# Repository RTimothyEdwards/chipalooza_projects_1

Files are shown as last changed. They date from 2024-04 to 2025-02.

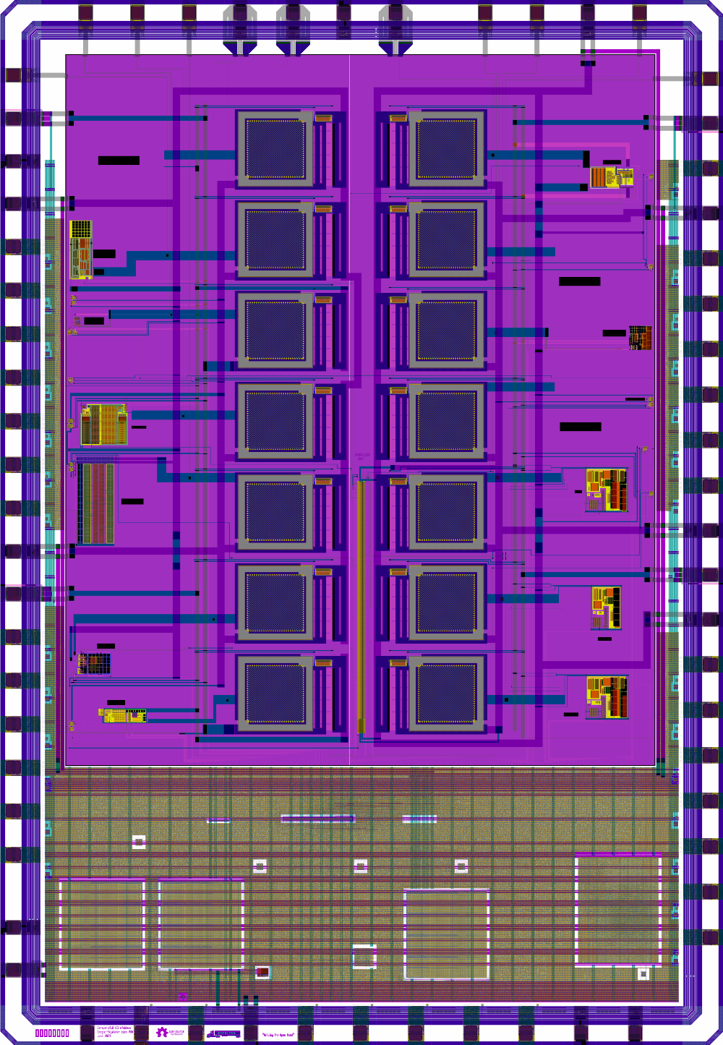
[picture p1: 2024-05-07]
doc/caravan.png

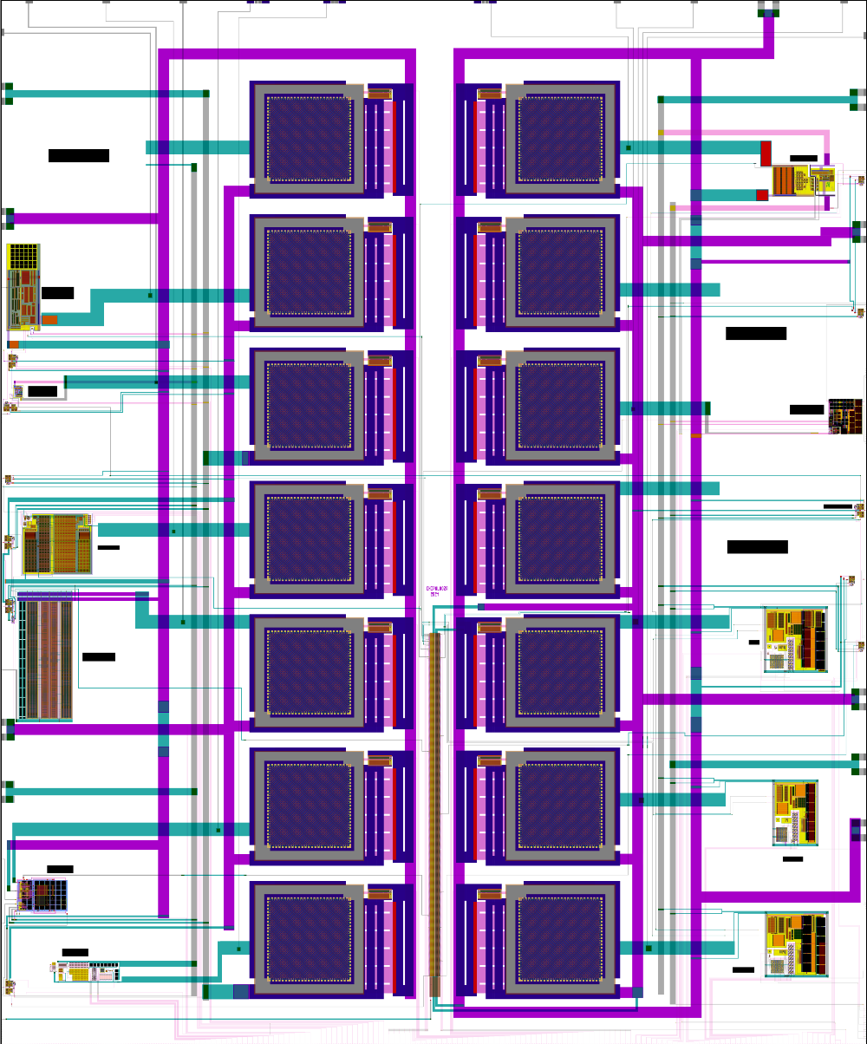
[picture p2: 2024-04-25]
doc/chipalooza_projects_1.png

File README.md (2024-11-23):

# Caravel Analog User

  

---

| :exclamation: Important Note            |
|-----------------------------------------|

This is the first test chip from the Chipalooza challenge 2024.
11 designs made it on the April tapeout.

The projects on this tapeout and their source URLs are as follows:

	1.  	High-speed crystal oscillator (4-16MHz)
		hsxo-cpz1 
		https://github.com/efabless/sky130_ht_ip__hsxo_cpz1 (forked)
		https://github.com/htfab/hsxo-cpz1
		Tamas Hubai

	2.  	Brownout detector
		sky130_ajc_ip__brownout
		https://github.com/efabless/sky130_ajc_ip__brownout (forked)
		https://github.com/ajcci/sky130_ajc_ip__brownout
		Robin Tsang

	3.  	Overvoltage detector
		sky130_ajc_ip__overvoltage
		https://github.com/efabless/sky130_ajc_ip__overvoltage (forked)
		https://github.com/ajcci/sky130_ajc_ip__overvoltage
		Robin Tsang

	4.  	Power-on-Reset
		sky130_ajc_ip__por
		https://github.com/efabless/sky130_ajc_ip__por (forked)
		https://github.com/ajcci/sky130_ajc_ip__por
		Robin Tsang

	5.  	Comparator
		sky130_ak_ip__comparator
		https://github.com/efabless/sky130_ak_ip__comparator (forked)
		https://github.com/andrewkkang/sky130_ak_ip__comparator
		Andrew Kang

	6.  	Low-speed crystal oscillator (32kHz)
		sky130_be_ip__lsxo
		https://github.com/efabless/sky130_be_ip__lsxo (forked)
		https://github.com/b-etz/sky130_be_ip__lsxo
		Brady Etz

	7.  	Temperature sensor
		sky130_od_ip__tempsensor
		https://github.com/efabless/sky130_od_ip__tempsensor (forked)
		https://github.com/ordicker/sky130_od_ip__tempsensor
		Or Dicker

	8.  	Low power operational amplifier
		sky130_rodovalho_ip__lpopamp
		https://github.com/efabless/sky130_rodovalho_ip__lpopamp (forked)
		https://github.com/lhrodovalho/sky130_rodovalho_ip__lpopamp
		Luis Henrique Rodovalho

	9.  	High gain-bandwidth operational amplifier
		sky130_td_ip__opamp_hp
		https://github.com/efabless/sky130_td_ip__opamp_hp (forked)
		https://github.com/tdextrous/sky130_td_ip__opamp_hp
		Thomas Dexter

	10. 	Overvoltage detector
		sky130_vbl_ip__overvoltage
		https://github.com/efabless/sky130_vbl_ip__overvoltage (forked)
		https://github.com/LDFranck/sky130_vbl_ip__overvoltage
		Lucas Franck, William Orlato, and Toni Tejada

	11.	Bandgap (not from Chipalooza)
		bandgap
		https://github.com/efabless/sky130_cw_ip (forked)
		https://github.com/christoph-weiser/mpw7
		Christoph Weiser

	12.	Power FET (not from Chipalooza)
		power_stage
		(in this repository)
		Weston Braun

	13.	Bias current generator (not from Chipalooza)
		bias_generator
		(in this repository)
		Tim Edwards

	14.	Ground-isolated analog switch (not from Chipalooza)
		isolated_switch_ena1v8
		(in this repository)
		Tim Edwards

(Documentation, including test instructions, still needs to be completed)

:---: | :---

Building:

Get the dependencies above by doing "make get_ip_blocks" in the top level
directory.  This will clone all of the IP blocks from various github
repository sources into the "dependencies" directory.

The test chip is generated in magic by running magic in the mag/ directory
and issuing the command "source construct_testchip.tcl".

Verifying:

In the top level directory, do "make run-precheck".  This requires at
least setting environment variables PDK_ROOT, PDK, and PRECHECK_ROOT.
If the PDK is installed with open_pdks, then PRECHECK_ROOT can be set
to open_pdks/sources/precheck_sky130.

Testing:

All projects are connected either to the logic analyzer (128 I/O bits) or
the GPIO pins.  Generally speaking, static control bits (enable and trim,
for example) are logic analyzer outputs.  Dynamic digital bits are routed
to GPIO digital outputs, while analog I/O are routed to the analog
connections of the GPIO.

Each power supply is routed through gated power pFETs so each project
can be powered individually.  Each power supply connection internally
is routed to a bare analog pin for monitoring the supply voltage of
the project.  Be aware that these are ESD-sensitive points!

Power supplies are enabled through a differential switch.  Due to
time constraints, the differential signals (enable, !enable) were
both routed to the logic analyzer.  Both bits need to be set
correctly.

Most projects take current biases which are distributed by a central
bias current generator circuit.  Various test point bias currents are
connected through ground-isolated switches to GPIO analog signals.

Project circuit blocks are described below, starting at the top left
corner of the chip and working counterclockwise around the chip
perimeter.

---

High Gain-Bandwidth Operational Amplifier  
(Thomas Dexter)  
Enable:  la_data_in[37]  
Bias:    100nA	when selected  
	Selection: la_data_in[40] = 0  
Upstream analog power supply: vdda2/vssa2  
Upstream digital power supply: vccd2/vssd2  
Power supply monitor:  io_analog[10] (pin GPIO 24) "mon_hgbw_opamp"  
Power supply enable: la_data_in[60]  
Amp output:  gpio_noesd[7] (pin GPIO 25) "hgbw_opamp_out"  
Amp negative input: gpio_analog[8] (pin GPIO 26) "hgbw_opamp_in-" when selected  
	Selection: la_data_in[36] = 1  
Amp positive input: gpio_analog[9] (pin GPIO 27) "hgbw_opamp_in+" when selected  
	Selection: la_data_in[34] = 1  

---

Temperature sensor  
(Or Dicker)  
Enable: la_data_in[35]  
Bias:  gpio_noesd[2] (pin GPIO 9) "1.2V_bias" (nominally 1.2V) when selected  
	Selection: la_data_in[122] = 1  
Upstream digital power supply: vccd2/vssd2  
Power supply monitor: io_analog[9] (pin GPIO 23) "mon_temp_sense"  
Power supply enable: la_data_in[58]  
Vbe1_out: gpio_analog[9] (pin GPIO 27) "temp_sense_vbe1" when selected  
	Selection: la_data_in[34] = 0  
Vbe2_out: gpio_analog[8] (pin GPIO 26) "temp_sense_vbe2" when selected  
	Selection: la_data_in[36] = 0  

---

Comparator  
(Andrew Kang)  
Enable: la_data_in[28]  
Hysteresis: la_data_in[29:30]  
Trim: la_data_in[25:27],la_data_in[33:31]  
Bias:	400nA	when selected  
	Selection:  la_data_in[44] = 0  
Upstream analog power supply: vdda2/vssa2  
Upstream digital power supply: vccd2/vssd2  
Power supply monitor: io_analog[8] (pin GPIO 22) "mon_comparator"  
Power supply enable: la_data_in[56]  
Comparator output: io_out[17] (pin GPIO 28) "comparator_out"  
Comparator negative input:  gpio_analog[12] (pin GPIO 30) "comparator_in-" when selected  
	Selection: la_data_in[22] = 1  
Comparator positive input:  gpio_analog[11] (pin GPIO 29) "comparator_in+" when selected  
	Selection: la_data_in[23] = 1  
	
---

Low power operational amplifier  
(Luis Henrique Rodovalho)  
Enable: la_data_in[21]  
Bias:  10uA when selected  
	Selection:  la_data_in[46] = 0  
Upstream analog power supply: vdda2/vssa2  
Upstream digital power supply: vccd2/vssd2  
Power supply monitor: io_analog[7] (pin GPIO 21) "mon_lpopamp"  
Power supply enable: la_data_in[54]  
Amplifier output:  gpio_analog[13] (pin GPIO 31) "lpopamp_out"  
Amplifier negative input: gpio_analog[11] (pin GPIO 29) "lpopamp_in-" when selected  
	Selection: la_data_in[23] = 0  
Amplifier positive input: gpio_analog[12] (pin GPIO 30) "lpopamp_in+" when selected  
	Selection: la_data_in[22] = 0  

---

High speed crystal oscillator  
(Tamas Hubai)  
Enable: la_data_in[19]  
Standby: la_data_in[20]  
Bias:  10uA when selected  
	Selection: la_data_in[47] = 0  
Upstream analog power supply: vdda2/vssa2  
Upstream digital power supply: vccd2/vssd2  
Power supply monitor: io_analog[6] (pin GPIO 20) "mon_hsxo"  
Power supply enable:  la_data_in[52]  
Oscillator out:  io_out[23] (pin GPIO 34) "hsxo_out"  
Crystal Xin:  gpio_analog[14] (pin GPIO 32) "hsxo_xin"  
Crystal Xout: gpio_analog[15] (pin GPIO 33) "hsxo_xout"  

---

Bandgap (Christoph Weiser)  
Enable: none (enable via power supply)  
Bias:  self-biased  
Trim: la_data_in[9,8,10,7,11,6,12,5,13,4,14,3,15,2,16,1]  
Upstream digital power supply: vccd2/vssd2  
Power supply monitor: io_analog[5] (pin GPIO 19) "mon_bandgap"  
Power supply enable: la_data_in[50]  
Bandgap output:  gpio_analog[16] (pin GPIO 34) "bandgap_out" when selected  
	Selection:  la_data_in[18] = 1  

---

Brownout detector (Robin Tsang)  
Enable: la_data_in[109]  
Bias: gpio_noesd[2] (pin GPIO 9) "1.2V_bias" (nominally 1.2V) when selected  
	Selection: la_data_in[122] = 0  
Bias: 200nA when selected  
	Selection: la_data_in[43] = 0  
Trip point select (otrip):  la_data_in[112:113,111]  
Trip point select (vtrip):  la_data_in[107:106,108]  
Force enable RC osc: la_data_in[115]  
Force disable RC osc: la_data_in[114]  
Force short oneshot: la_data_in[116]  
Current source select: la_data_in[110]  
Upstream analog power supply: vdda1/vssa1  
Upstream digital power supply: vccd1/vssd1  
Power supply monitor: io_analog[0] (pin GPIO 14) "mon_brownout"  
Power supply enable: la_data_in[77]  
Outb: io_out[0] (pin GPIO 0) "brownout_outb"  
Dcomp: io_out[1] (pin GPIO 1) "brownout_dcomp"  
Vunder: io_out[5] (pin GPIO 5) "brownout_vunder"  
Timed out: la_data_out[117]  

---

Overvoltage detector (Robin Tsang)  
Enable: la_data_in[100]  
Bias: gpio_noesd[2] (pin GPIO 9) "1.2V_bias" (nominally 1.2V) when selected  
	Selection: la_data_in[122] = 0  
Bias: 200nA when selected  
	Selection: la_data_in[42] = 0  
Trip point select (otrip):  la_data_in[105:102]  
Current source select: la_data_in[101]  
Upstream analog power supply: vdda1/vssa1  
Upstream digital power supply: vccd1/vssd1  
Power supply monitor: io_analog[1] (pin GPIO 15) "mon_overvoltage1"  
Power supply enable: la_data_in[75]  
Ovout: io_out[6] (pin GPIO 6) "overvoltage1_ovout"  

---

Power-on-reset (Robin Tsang)  
Bias: gpio_noesd[2] (pin GPIO 9) "1.2V_bias" (nominally 1.2V) when selected  
	Selection: la_data_in[122] = 0  
Bias: 200nA when selected  
	Selection: la_data_in[41] = 0  
Trip point select (otrip): la_data_in[96:98]  
Force PDN: la_data_in[94]  
Force enable RC osc: la_data_in[93]  
Force disable RC osc: la_data_in[92]  
Force short oneshot: la_data_in[99]  
Current source select: la_data_in[95]  
Upstream analog power supply: vdda1/vssa1  
Upstream digital power supply: vccd1/vssd1  
Power supply monitor: io_analog[2] (pin GPIO 16) "mon_por"  
Power supply enable: la_data_in[73]  
POR: io_out[7] (pin GPIO 7) "por_out"  
PORb: io_out[8] (pin GPIO 8) "por_outb"  
Osc_clk: io_out[3] (pin GPIO 3) "por_osc_clk"  
Dcomp: io_out[2] (pin GPIO 2) "por_dcomp"  
Pwup_filt: io_out[4] (pin GPIO 4) "por_pwup_filt"  
Startup timed out: la_data_out[120]  
POR timed out: la_data_out[119]  

---

Low-speed (32kHz) crystal oscillator (Brady Etz)  
Enable: la_data_in[86]  
Standby: la_data_in[85]  
Bias: 50nA when selected  
	Selection: la_data_in[39] = 0  
Upstream analog power supply: vdda1/vssa1  
Upstream digital power supply: vccd1/vssd1  
Power supply monitor: io_analog[3] (pin GPIO 17) "mon_lsxo"  
Power supply enable: la_data_in[69]  
Dout: io_out[12] (pin GPIO 12) "lsxo_out"  
Crystal XIn: gpio_noesd[3] (pin GPIO 10) "lsxo_xin"  
Crystal XOut: gpio_noesd[4] (pin GPIO 11) "lsxs_xout"  

---

Overvoltage detector (Lucas Franck & William Orlato)  
Enable: la_data_in[91]  
Bias: gpio_noesd[2] (pin GPIO 9) "1.2V_bias" (nominally 1.2V) when selected  
	Selection: la_data_in[122] = 1  
Bias: 600nA when selected  
	Selection: la_data_in[45] = 0  
Trip point select (vtrip): la_data_in[87:90]  
Upstream analog power supply: vdda1/vssa1  
Upstream digital power supply: vccd1/vssd1  
Power supply monitor: io_analog[4] (pin GPIO 18) "mon_overvoltage2"  
Power supply enable: la_data_in[65]  
OVout: io_out[13] (pin GPIO 13) "overvoltage2_out"  

---

All bias currents are regulated by an input bias voltage which is
nominally 3.3V but may be adjusted up or down to trim the bias
(limit max. voltage VDDIO + 0.3V to avoid forward biasing the ESD
diodes into the power supply).  
Bias in: gpio_analog[17] (pin GPIO 35) "bias_trim_in"  

---

Three power FETs are unused but should be kept disabled:  
Enable:  la_data_in[62], la_data_in[67], la_data_in[71]  

---

The bias generator has a master enable signal that will enable
all bias currents:  

Enable bias generator:  la_data_in[79]   

It also has a separate disable signal for the sources (which is
all of the biases used by projects on this chip):  

Disable bias generator sources:  la_data_in[48]   

---

These current sources/sinks are multiplexed to analog pins not otherwise
being used for projects.  The "enable" or "disable" bit enables or disables
the current bias, and "selection" connects it to the associated pin:  

100nA source (test0): gpio_analog[16] (pin GPIO 34) when selected  
	Disable: la_data_in[49]  
	Selection: la_data_in[18] = 0 (at pin)  

100nA source (test1): gpio_analog[10] (pin GPIO 28) when selected  
	Disable: la_data_in[38]  
	Selection: la_data_in[17] = 1 (at pin)  

100nA sink (test1): gpio_analog[6] (pin GPIO 13) when selected  
	Enable:  la_data_in[84]  
	Selection: la_data_in[124] = 1 (at pin)  

3.7uA sink (sink_3700): gpio_analog[5] (pin GPIO 12) when selected  
	Enable:  la_data_in[83]  
	Selection: la_data_in[123] = 1 (at pin)  

5.0uA sink (sink_5000_1): gpio_analog[1] (pin GPIO 8) when selected  
	Enable:  la_data_in[81]  
	Selection: la_data_in[121] = 1 (at pin)  

100nA sink (test0): gpio_analog[0] (pin GPIO 7) when selected  
	Enable:  la_data_in[78]  
	Selection: la_data_in[118] = 1 (at pin)  

---

Refer to [README](docs/source/index.rst) for this sample project documentation.   

Refer to docs/chipalooza_testchip1.pdf (.ps) for a package pinout drawing.  

---

Chip QFN-64 package pinout:

Pin  Signal(s)  
 1   vssa2  
 2   mprj_io[25] hgbw_opamp_out  
 3   mprj_io[26] hgbw_opamp_in- temp_sense_vbe2  
 4   mprj_io[27] hgbw_opamp_in+ temp_sense_vbe1  
 5   mprj_io[28] comparator_out source_100_1  
 6   mprj_io[29] comparator_in+ lpopamp_in-  
 7   mprj_io[30] comparator_in- lpopamp_in+  
 8   mprj_io[31] lpopamp_out  
 9   vdda2  
10   vssd2  
11   mprj_io[32] hsxo_xin  
12   mprj_io[33] hsxo_xout  
13   mprj_io[34] hsxo_out  bandgap_out source_100_0  
14   mprj_io[35] bias_trim_in  
15   mprj_io[36]  
16   mprj_io[37]  
17   vddio  
18   vccd  
19   N/C  
20   vssa  
21   resetb  
22   clock  
23   vssd  
24   flash_csb  
25   flash_clk  
26   flash_io0  
27   flash_io1  
28   gpio  
29   vssio  
30   vdda  
31   mprj_io[0] brownout_outb  
32   mprj_io[1] brownout_dcomp  
37   mprj_io[2] por_dcomp  
34   mprj_io[3] por_osc_clk  
35   mprj_io[4] por_pwup_filt  
36   mprj_io[5] brownout_vunder  
37   mprj_io[6] overvoltage1_ovout  
38   vssa1  
39   vssd1  
40   vdda1  
41   mprj_io[7] por_out  sink_100_0  
42   mprj_io[8] por_outb  
43   mprj_io[9]  1.2V_bias  
44   mprj_io[10] lsxo_xin  
45   mprj_io[11] lsxo_xout  
46   mprj_io[12] lsxo_out  sink_3700  
47   vdda1  
48   mprj_io[13] overvoltage2_out  sink_100_1  
49   vccd1  
50   mprj_io[14] mon_brownout  
51   mprj_io[15] mon_overvoltage1  
52   vssa1  
53   mprj_io[16] mon_por  
54   mprj_io[17] mon_lsxo  
55   mprj_io[18] mon_overvoltage2  
56   vssio  
57   mprj_io[19] mon_bandgap  
58   mprj_io[20] mon_hsxo  
59   mprj_io[21] mon_lpopamp  
60   mprj_io[22] mon_comparator  
61   mprj_io[23] mon_temp_sense  
62   mprj_io[24] mon_hgbw_opamp  
63   vccd2  
64   vddio  

---

NOTES:  The following pins have dual analog and digital functions.  The
analog function is enabled/disabled by a ground isolation swtch, and the
digital function is enabled/disabled by configuring the GPIO from
software.

pin 41:  por_out (digital), sink_100_0 (analog)  
pin 42:  porb_out (digital), sink_5000_1 (analog)  
pin 46:  lsxo_out (digital), sink_3700 (analog)  
pin 5:   comparator_out (digital), source_100_1 (analog)  
pin 13:  hsxo_out (digital), bandgap_out, source_100_0 (analog, multiplexed)*  

*Because the analog on pin 13 is multiplexed, the analog can only be
 completely disabled by selecting source_100_0 as the multiplexer input and
 then disabling the current source.  This is not ideal but should not
 interfere with the HSXO output.

---

Logic analyzer map:

la_data_in[16:1]  Bandgap trim (not in order)  
la_data_in[17]	  Select source_test_1 at pin  
la_data_in[18]    Select bandgap_out (1) or source_test_0 (0)  
la_data_in[19]	  HSXO enable  
la_data_in[20]	  HSXO standby  
la_data_in[21]	  LP opamp enable  
la_data_in[22]	  Select comparator_in- (1) or lpopamp_in+ (0)  
la_data_in[23]	  Select comparator_in+ (1) or lpopamp_in- (0)  
la_data_in[27:25] Comparator trim  
la_data_in[28]	  Comparator enable  
la_data_in[30:29] Comparator hysteresis  
la_data_in[33:31] Comparator trim  
la_data_in[34]	  Select hgbw_opamp_in+ (1) or temp_sense_vbe1 (0)  
la_data_in[35]	  Temperature sensor enable  
la_data_in[36]	  Select hgbw_opamp_in- (1) or temp_sense_vbe2 (0)  
la_data_in[37]	  HGBW op amp enable  
la_data_in[38]	  Disable source_test_1 at bias  
la_data_in[39]	  Disable LSXO 50nA bias  
la_data_in[40] 	  Disable HGBW op amp 100nA bias  
la_data_in[41] 	  Disable POR 200nA bias  
la_data_in[42]	  Disable Overvoltage1 200nA bias  
la_data_in[43]	  Disable Brownout 200nA bias  
la_data_in[44]	  Disable Comparator 400nA bias  
la_data_in[45]	  Disable Overvoltage2 600nA bias  
la_data_in[46]	  Disable LP op amp 10uA bias  
la_data_in[47]	  Disable HSXO 10uA bias  
la_data_in[48] 	  Disable bias generator sources  
la_data_in[49]	  Disable source_test_0  
la_data_in[50]	  Enable Bandgap power supply  
la_data_in[52]	  Enable HSXO power supply  
la_data_in[54]	  Enable LP op amp power supply  
la_data_in[56]	  Enable Comparator power supply  
la_data_in[58]	  Enable Temperature sensor power supply  
la_data_in[60]	  Enable HGBW op amp power supply  
la_data_in[62]	  (Enable unused power supply)  
la_data_in[65]	  Enable Overvoltage2 power supply  
la_data_in[67]	  (Enable unused power supply)  
la_data_in[69]	  Enable LSXO power supply  
la_data_in[71]	  (Enable unused power supply)  
la_data_in[73]	  Enable POR power supply  
la_data_in[75]	  Enable Overvoltage1 power supply  
la_data_in[77]	  Enable Brownout power supply  
la_data_in[78]	  Enable sink_test_0  
la_data_in[79]	  Enable bias generator (master enable)  
la_data_in[80]	  Enable sink_5000_0 (unused)  
la_data_in[81]	  Enable sink_5000_1  
la_data_in[82]	  Enable sink_5000_2 (unused)  
la_data_in[83]	  Enable sink_3700  
la_data_in[84]	  Enable sink_test_1  
la_data_in[85]    LSXO Standby  
la_data_in[86]    LSXO Enable  
la_data_in[90:87] Overvoltage2 trip point selection  
la_data_in[91]	  Overvoltage2 enable  
la_data_in[92]	  POR force disable RC oscillator  
la_data_in[93]	  POR force enable RC oscillator  
la_data_in[94]	  POR force PDN  
la_data_in[95]	  POR current source select  
la_data_in[98:96] POR trip point select  
la_data_in[99]	  POR force short oneshot  
la_data_in[100]	  Overvoltage1 enable  
la_data_in[101]	  Overvoltage1 current source select  
la_data_in[105:102] Overvoltage1 trip point select  
la_data_in[108:106] Brownout trip point (vtrip) select  
la_data_in[109]	  Brownout enable  
la_data_in[110]	  Brownout current source select  
la_data_in[113:111] Brownout trip point (otrip) select  
la_data_in[114]	  Brownout force disable RC oscillator  
la_data_in[115]	  Brownout force enable RC oscillator  
la_data_in[116]	  Brownout force short oneshot  
la_data_out[117]  Brownout timed out  
la_data_in[118]	  Select sink_test_0 at pin  
la_data_out[119]  POR timed out  
la_data_out[120]  POR startup timed out  
la_data_in[121]	  Select sink_5000_1 at pin  
la_data_in[122]	  Select 1.2V bias (see above)  
la_data_in[123]	  Select sink_3700 at pin  
la_data_in[124]	  Select sink_test_1 at pin  
la_data_in[125]	  Enable sink_2000 (unused)  

---

Test plan:

Write a software routine to run on flash that communicates via UART.
Because projects use GPIO[1-4] (housekeeping SPI) and GPIO[5-6] (UART),
use pin GPIO[36] to toggle between the UART and project I/O, and use
pin GPIO[37] to toggle between the housekeeping SPI and project I/O.
Program should communicate with the host computer to select and
identify projects, and to set trim and other configuration bits as
needed.

For helping with testbench scripting, an API has been defined in
the `firmware/` directory.  File `chipalooza_defs.h` define all of the
bit mask values into the logic analyzer data arrays.  File
`chipalooza_utils.c` defines a set of routines for accessing each
of the projects.  Note that this only defines access to each project
for the configuration that is set or read from the logic analyzer
data array.  Check the connections of each project referenced above
for information on what I/O pins to connect to for each project,
which power supplies need to be enabled, and any other board-level
inputs or outputs required.

chipalooza_utils.c API:

Bandgap:

	void bandgap_powerup()

	void bandgap_powerdown()

	void bandgap_select_output()

	void bandgap_set_trim(uint16_t value)

HSXO:

	void hsxo_powerup()

	void hsxo_powerdown()

	void hsxo_enable()

	void hsxo_disable()

	void hsxo_run()

	void hsxo_standby()

	void hsxo_bias_enable()

	void hsxo_bias_disable()

LSXO:

	void lsxo_powerup()

	void lsxo_powerdown()

	void lsxo_enable()

	void lsxo_disable()

	void lsxo_run()

	void lsxo_standby()

	void lsxo_bias_enable()

	void lsxo_bias_disable()

LP opamp:

	void lp_opamp_powerup()

	void lp_opamp_powerdown()

	void lp_opamp_enable()

	void lp_opamp_disable()

	void lp_opamp_enable_inputs()

	void lp_opamp_bias_enable()

	void lp_opamp_bias_disable()

Comparator:

	void comparator_powerup()

	void comparator_powerdown()

	void comparator_enable()

	void comparator_disable()

	void comparator_enable_inputs()

	void comparator_bias_enable()

	void comparator_bias_disable()

	void comparator_set_hyst(uint8_t value)

	void comparator_set_trim(uint8_t value)

Temperature sensor:

	void tempsense_powerup()

	void tempsense_powerdown()

	void tempsense_enable()

	void tempsense_disable()

	void tempsense_enable_outputs()

HGBW op-amp:

	void hgbw_opamp_powerup()

	void hgbw_opamp_powerdown()

	void hgbw_opamp_enable()

	void hgbw_opamp_disable()

	void hgbw_opamp_enable_inputs()

	void hgbw_opamp_bias_enable()

	void hgbw_opamp_bias_disable()

Overvoltage detector (2):

	void overvoltage2_powerup()

	void overvoltage2_powerdown()

	void overvoltage2_enable()

	void overvoltage2_disable()

	void overvoltage2_bias_enable()

	void overvoltage2_bias_disable()

	void overvoltage2_set_trippoint(uint8_t value)

POR:

	void por_powerup()

	void por_powerdown()

	void por_vbg_enable()

	void por_vbg_disable()

	void por_bias_enable()

	void por_bias_disable()

	void por_osc_default()

	void por_force_osc_on()

	void por_force_osc_off()

	void por_pdn_default()

	void por_force_pdn()

	void por_select_external_bias()

	void por_select_internal_bias()

	void por_oneshot_mode()

	void por_continuous_mode()

	void por_set_trippoint(uint8_t value)

	uint8_t por_get_timeout()

	uint8_t por_get_startup_timeout()

Overvoltage detector (1):

	void overvoltage1_powerup()

	void overvoltage1_powerdown()

	void overvoltage1_enable()

	void overvoltage1_disable()

	void overvoltage1_bias_enable()

	void overvoltage1_bias_disable()

	void overvoltage1_select_external_bias()

	void overvoltage1_select_internal_bias()

	void overvoltage1_set_trippoint(uint8_t value)

Brownout detector:

	void brownout_powerup()

	void brownout_powerdown()

	void brownout_vbg_enable()

	void brownout_vbg_disable()

	void brownout_bias_enable()

	void brownout_bias_disable()

	void brownout_select_external_bias()

	void brownout_select_internal_bias()

	void brownout_set_vtrippoint(uint8_t value)

	void brownout_set_otrippoint(uint8_t value)

	void brownout_osc_default()

	void brownout_force_osc_on()

	void brownout_force_osc_off()

	void brownout_oneshot_mode()

	void brownout_continuous_mode()

	uint8_t brownout_get_timeout()

Bias generator:

	void biasgen_enable()

	void biasgen_disable()

	void biasgen_sources_enable()

	void biasgen_sources_disable()

Bias generator test outputs:

	void biasgen_source_test0_enable()

	void biasgen_source_test0_disable()

	void biasgen_source_test0_enable_output()

	void biasgen_source_test0_disable_output()

	void biasgen_source_test1_enable()

	void biasgen_source_test1_disable()

	void biasgen_source_test1_enable_output()

	void biasgen_source_test1_disable_output()

	void biasgen_sink_test0_enable()

	void biasgen_sink_test0_disable()

	void biasgen_sink_test0_enable_output()

	void biasgen_sink_test0_disable_output()

	void biasgen_sink_test1_enable()

	void biasgen_sink_test1_disable()

	void biasgen_sink_test1_enable_output()

	void biasgen_sink_test1_disable_output()

	void biasgen_sink_test_3700_enable()

	void biasgen_sink_test_3700_disable()

	void biasgen_sink_test_3700_enable_output()

	void biasgen_sink_test_3700_disable_output()

	void biasgen_sink_test_5000_enable()

	void biasgen_sink_test_5000_disable()

	void biasgen_sink_test_5000_enable_output()

	void biasgen_sink_test_5000_disable_output()

Power switching:

	void powerdown_unused()

	void powerdown_all()

General:

	void init_logic_analyzer()

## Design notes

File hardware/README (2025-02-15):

The LSXO and HSXO on the test chip will perform poorly unless the
crystals and their load caps are placed close to the package pins
where the crystal inputs and outputs are located.  The existing
M.2 daughtercard for the chipIgnite development board does not
have pads for additional components.

This alternative daughter card is specifically for use with this
project and has pads for the low speed (32kHz) crystal on the
front side (X2), and pads for a surface mount high-speed crystal
(8-16 MHz) on the back side (X1) with a footprint that will
accommodate several sizes (2x1.6, 2.5x2, or 3.2x2.5).  For the
lower speeds (4 and 6 MHz), an additonal through-hole mount
(X3) is provided (requires zero-ohm resistors on JP1 and JP2).

Thanks to Brady Etz (who designed the LSXO for Chipalooza) for
the daughterboard design.

For the LSXO:
Suggested vendor:  Mouser Electronics
Suggested parts:
	ECS-.327-12.5-12R-C [CL=12.5pF]
	LFXTAL062558 [CL=9pF]
	ABS06-32.768KHZ-6-1 [CL=6pF]

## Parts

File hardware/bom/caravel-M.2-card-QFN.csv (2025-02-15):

Id | Designator | Footprint | Quantity | Designation | Supplier and ref
1 | C8,C9,C6,C1,C2,C7,C3,C5,C4 | C_0402_1005Metric | 9 | 0.1uf
2 | T1 | logo_small | 1 | Logo
3 | T2 | ef_logo | 1 | Logo
4 | U1 | QFN-64-1EP_9x9mm_P0.5mm_EP7.65x7.65mm | 1 | Caravel
5 | J1 | MicroMod-M.2-CARD-E-22 | 1 | MICROMOD-2222-Generic

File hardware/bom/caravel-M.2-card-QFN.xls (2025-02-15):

Designator | Qty | Value | Part number | Vendor
C1, C2, C3, C4, C5, C6, C7, C8, C9 | 9 | 0.1uf | CC0402KRX7R9BB104 | DK
U1, | 1 | Caravel |  | Customer provided

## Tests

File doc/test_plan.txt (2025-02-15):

Chipalooza Test Chip #1 test plan
---------------------------------------------

--------------------------------
A. Infrastructure
--------------------------------

1. Smoke tests

	a. General comment:  All power FETs are connected to analog
	   pads without ESD protection.  Use caution when handling
	   parts.

	b. Test that circuitry does not interfere with the Caravel
	   management processor.

	c. With all logic analyzer bits off, the two user analog power
	   supplies should be able to be set to 3.3V and there should
	   be no additional power draw, because all circuits are
	   disconnected from the power supplies.

	   NOTE:  The current bias generator is connected directly to
	   VDDA1 and does not pass through a power FET;  it is the
	   only circuit other than the switches that is so connected.
	   However, it has numerous enable signals and should not draw
	   any supply current when everything is disabled.  The
	   switches likewise do not consume power (other than
	   negligible leakage power).

	d. The user digital power supplies should not create additional
	   power draw either, because all digital controls should either
	   be driving level shifters in each circuit, except for those
	   circuits which operate at 1.8V, for which the 1.8V supply is
	   drawn through a power FET.

2. Communication

	The brownout detector and the POR have test outputs connected
	to GPIO pins 1 to 4;  the brownout and overvoltage detectors
	have test outputs on GPIO pins 5 and 6.  This makes these
	signals difficult to manage;  all other projects can be reached
	by software through either UART or housekeeping SPI.

	Recommended:  Use the otherwise unused pin GPIO[36] as an input
	switch to toggle between the user project and the UART.  Use
	GPIO[37] as an input switch to toggle between the user project
	and the housekeeping SPI.

	Because the housekeeping SPI does not have direct access to the
	logic analyzer, control of the chip will have to be done through
	a program running on the management processor which may either
	communicate through UART or through the housekeeping SPI (by
	monitoring an inactive register such as the DLL trim).  

	The vast majority of logic analyzer signals are outputs
	driving block configuration.  A simple interface can simply
	specify a logic analyzer bit (see README.md for a list of
	bits used) to be set or cleared.  A handful of bits in the
	upper register range are inputs that need to be queried;
	these can be sampled and redirected to an unused output.
	Another approach would be to have a test program for each
	circuit;  however, the more general approach is better
	because it is only necessary to run a script to drive the
	UART or housekeeping SPI, not to program the flash.

3. Ground-isolated analog switch

	Many circuit outputs are routed through switches because the
	number of pads on the Caravel chip is too limited to test all
	of the necessary signals.  This particular test chip does not
	have a loopback test that can be used to measure the switch
	resistance (the 2nd test chip has that, and it will be measured
	later).  It is probably possible to get a reasonable estimate
	of the switch resistance from the bias generator test outputs
	(test TBD).

4. Power FET

	Every test circuit operates on its own power FET, isolating
	it from the power pads and from other test circuits.

	Each power FET (except for a few) has its output connected
	by a small wire to one of the bare analog pads.  This pad
	can be used to monitor the voltage at the power FET's output.
	By measuring current through the analog power supply (or
	in a few cases, digital power supply) and measuring the
	difference between the voltage at the power supply input
	and the voltage at the power FET monitoring pin, the
	resistance of the power FET can be calculated.

	A few power FETs are not being used;  however, these do not
	have monitor pins and so their output cannot be either
	connected to anything or measured.  They have enable signals
	but should not be enabled.

5. Bias current generator

	The bias current generator supplied bias currents to many of
	the other blocks.  The bias currents are in multiple units
	of a nominal unit current of 50nA, which can be either a
	source or a sink.

	To ensure correct operation of the test circuits, the bias
	generator has test outputs to check the output at different
	magnitudes and source and sink.

	The bias generator has multiple enable controls:

	Enable bias generator:  la_data_in[79] = 1
	
	This enables both sources and sinks.  The sources have an
	additional disable signal:  la_data_in[48] = 1.  This does
	not affect current sinks.

	Note that all sources have a "disable" signal rather than
	an "enable" signal.

	There are 6 test currents that should be enabled and
	measured (see README.md):

	Current test point			resistor
	100nA source (two testpoints)		10Mohms to ground
	100nA sink				10Mohms to 3.3V
	3.7uA sink				270kohms to 3.3V
	5.0uA sink				200kohms to 3.3V
	100nA sink				10Mohms to 3.3V

	The two 100nA sources are on opposite ends of the bias generator
	and can be used to measure any current difference across the
	length of the circuit.

	Sources should be connected with a resistor to ground.  Sinks
	should be connected with a resistor to power (3.3V).  Resistor
	values producing a 1V drop across the resistor are given in
	the table above;  these are just suggestions.

	TEST:  Measure currents at all test points and compare to
	expected value, and compare across samples.

6. Bandgap (CW)

	This bandgap circuit has no enable signal and is self-biased.
	It will be powered on when the corresponding power FET is
	enabled.  NOTE:  The power supply for this circuit is 1.8V
	and comes from the digital supply (vccd2).

	Measure current draw of the circuit
	Measure voltage drop at the power FET monitor pin
	Measure the bandgap output voltage at selected trim values
	(16-bit trim).

	Apply sinusoid at 1kHz to the power supply and measure
	rejection at the bandgap output

	Load output with resistances and measure load regulation.

	Measure output vs. power supply voltage.

	(With temperature force unit) Measure output vs. temperature.

--------------------------------
B. Power system
--------------------------------

7. Overvoltage detector (VBL)

	The overvoltage detector is a straightforward implementation
	with a voltage divider with a selection of voltages,
	compared against the bandgap voltage, making the circuit
	output independent of the voltage both driving the circuit
	and being tested.

	The "bandgap voltage" should be applied externally from a
	1.2V source.

	There are four trim bits to select the voltage trip point.
	These should each be tested independently.  At trim 4'b0000,
	the trip point is 3.3V, up to trim 4'b1111 with a trip point
	of 5.5V.

	5.5V is the maximum rating of the I/O pads and care should be
	taken when operating in this range.

	For each trim value, measure both the voltage needed to trigger
	the overvoltage alarm, and the voltage needed to turn it off.

	Measure the current used by the circuit both when enabled and
	disabled.
	
8. Brownout detector

	This circuit is designed to produce an alarm signal `out` (asserted low)
	when the power supply `avdd` falls below a selectable trip voltage via
	`otrip[2:0]`, ranging from 2.4V to 3.0V.

	May need to contact designer for details of some of the test signals.
	Most test signals are connected, although some are only available
	through the logic analoger.

	The circuit has its own bias generator and internal clock generator.
	The internal bias generator can be overridden in favor of an
	external bias (irsc_sel) which is connected to the on-chip bias
	generator.

	The circuit is designed to have two separate detectors at two
	different voltages.  Once can be used to produce an alarm while
	the other can be used to force a brownout reset through an interrupt.
	For the purposes of testing, these are two independent detectors.

	The two main outputs are "vunder" and "brout_filt".  The latter
	has a schmitt trigger to provide some hysteresis.  The unfiltered
	version of "brout_filt" is the signal "dcomp".  All output signals
	are in the 1.8V digital domain.

	The "vunder" trip point is controlled by setting "vtrip[2:0]".  The
	"brout_filt" trip point is controlled by setting "otrip[2:0]".

	Measure the three outputs vs. voltage over trip point settings.
	Measure glitch rejection.
	Measure current consumption in enabled and disabled modes.

9. Overvoltage detector (AJACCI)

	The overvoltage detector is a straightforward implementation
	with a voltage divider with a selection of voltages,
	compared against the bandgap voltage, making the circuit
	output independent of the voltage both driving the circuit
	and being tested.  The circuit has its own current bias,
	or the current bias can be applied from an external source
	(in the test chip, this comes from the bias current generator).

	The "bandgap voltage" should be applied externally from a
	1.2V source.

	There are four trim bits to select the voltage trip point.
	These should each be tested independently.  At trim 4'b0000,
	the trip point is 3.3V, up to trim 4'b1111 with a trip point
	of 5.5V.

	5.5V is the maximum rating of the I/O pads and care should be
	taken when operating in this range.

	For each trim value, measure both the voltage needed to trigger
	the overvoltage alarm, and the voltage needed to turn it off.

	Measure the current used by the circuit both when enabled and
	disabled.

10. Power-on-reset

	The power-on-reset circuit is essentially the same circuit as
	the brownout detector (see above) without the second channel
	and output.  All measurements should be the same as for the
	brownout detector.  However, unlike the brownout detector,
	the circuit startup is important:

	Measure circuit behavior as the power supply ramps from 0 to
	(full range = 2.5 to 3.3?).  Check behavior for slow ramps
	(10ms or more) and fast ramps (up to 2us).  Check behavior
	when analog supply is raised first, and check behavior when
	digital supply is raised first, and when both operate
	simultaneously.

	Use the bandgap from the test chip to provide the bandgap
	voltage to reflect the delay in the bandgap voltage due
	to the powering of the bandgap.  This should be done with
	the bandgap power supply being raised along with the 3.3V
	power supply, with varying delay between the 3.3V power
	supply and the 1.8V bandgap power supply (which should be
	considered independent of the 1.8V digital power supply).

--------------------------------
C. Timing system
--------------------------------

11. High-speed crystal oscillator

	Requires a crystal and load capacitors.  Need to check for
	multiple crystals in the range 4 to 16 MHz.

	Controls are "enable" and "standby".

	When "standby" is on, it should be possible to measure
	the current draw on the supply (the oscillator is running)
	but no output should be present.  If "standby" is released,
	operation should be immediate.

	Measure startup time of the oscillator when "standby" is
	not used ("enable" only).

	Measure current draw of the oscillator in disabled, standby,
	and enabled modes.

	Check startup and operation over power supply variation of +/-10%

	(With temperature force unit) Check startup and operation over
	commercial temperature range (-40C to 100C).

12. Low-speed crystal oscillator

	Tests are same as above for the high-speed crystal oscillator,
	except that the external crystal is 32.768kHz and is a fixed
	value.

--------------------------------
D. Amplifiers
--------------------------------

13. Low power operational amplifier

	This circuit has 3.3V enable and enable-bar which are handled
	outside of the circuit with a level shifter buffer and inverter.
	There are no controls other than the enable.  Inputs and outputs
	are connected directly to GPIO pins (analog function).

	Measure under conditions of varying power supply and temperature
	(when a temperature force unit is available):

	Input offset, gain, PSRR, CMRR, total current on supply (enabled
	and disabled), total current to output (source and sink).

14. High gain-bandwidth operational amplifier

	There are no controls other than enable.  Inputs and outputs
	are connected directly to GPIO pins (analog function).

	Measure under conditions of varying power supply and temperature
	(when a temperature force unit is available):

	Input offset, gain, PSRR, CMRR, total current on supply (enabled
	and disabled), total current to output (source and sink).  

15. Comparator

	In addition to the enable, this circuit has two bits of
	hysteresis control and six bits of trim control.  The trim
	function is in two sets of 3 bits.  Trim[2:0] controls trim
	of the N-side while trim[5:3] controls trim of the P-side.

	Measure hysteresis:  00 = none, 01 = 10mV, 11 = 50mV (10 = ??)

	Like the amplifiers, inputs and output are connected directly
	to GPIO pins, although the output, being in the digital domain,
	is connected to a digital output buffer.

	Measure under conditions of varying power supply and temperature
	(when a temperature force unit is available):

	Input offset (vs. trim), hysteresis (vs. hyst. trim), gain, PSRR,
	CMRR, total current on supply (enabled and disabled).

--------------------------------
E. Sensors
--------------------------------

16. Temperature sensor

	The temperature sensor operates on a 1.8V supply.

	The temperature sensor has two low-voltage outputs.
	Temperature must be calculated from the two outputs Vbe1 and Vbe2.
	Both outputs are in the range of around 1/2V to 1V.

	T = 714.015 * ((10.7906 / (10.7906 + (Vbe1 / (Vbe2 - Vbe1)))) - 259.802)

	Temperature reading should be stable if the bandgap voltage is
	stable.  Measure temperature output over supply voltage.  With
	temperature force unit, measure over temperature.  Without
	temperature force unit, use a hot air blower and estimate
	temperature from the ambient reading with a thermocouple.

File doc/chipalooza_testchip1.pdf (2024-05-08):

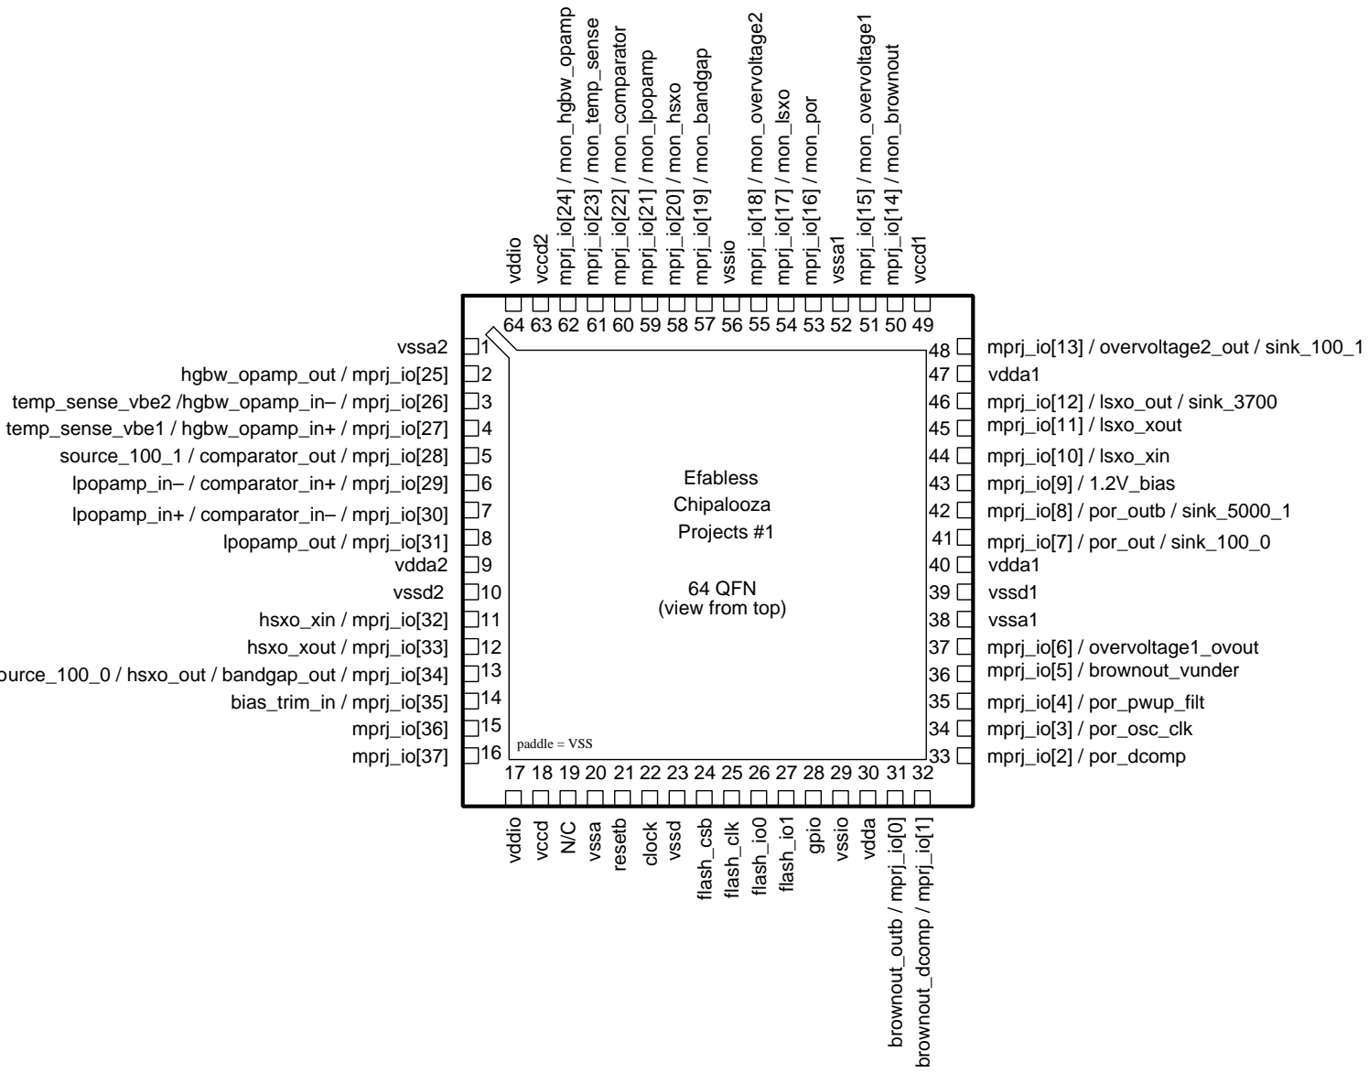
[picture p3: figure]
Chipalooza; 64 QFN (view from top); paddle = VSS 16; Efabless; Projects #1; mprj_io[23] / mon_temp_sense; mprj_io[22] / mon_comparator; mprj_io[21] / mon_lpopamp; mprj_io[20] / mon_hsxo; mprj_io[19] / mon_bandgap; vssio; mprj_io[18] / mon_overvoltage2; mprj_io[17] / mon_lsxo; mprj_io[16] / mon_por; vssa1; mprj_io[15] / mon_overvoltage1; brownout_outb / mprj_io[0]; brownout_dcomp / mprj_io[1]; mprj_io[2] / por_dcomp; mprj_io[3] / por_osc_clk; mprj_io[4] / por_pwup_filt; mprj_io[5] / brownout_vunder; mprj_io[6] / overvoltage1_ovout; vssd1; vdda1; mprj_io[7] / por_out / sink_100_0; mprj_io[8] / por_outb / sink_5000_1; mprj_io[9] / 1.2V_bias; mprj_io[10] / lsxo_xin; mprj_io[11] / lsxo_xout; mprj_io[12] / lsxo_out / sink_3700; mprj_io[13] / overvoltage2_out / sink_100_1; mprj_io[14] / mon_brownout; vccd1; vssa; resetb; clock; vssd; flash_csb; flash_clk; flash_io0; flash_io1; gpio; vdda; mprj_io[24] / mon_hgbw_opamp; hgbw_opamp_out / mprj_io[25] temp_sense_vbe2 /hgbw_opamp_in– / mprj_io[26] temp_sense_vbe1 / hgbw_opamp_in+ / mprj_io[27] source_100_1 / comparator_out / mprj_io[28] lpopamp_in– / comparator_in+ / mprj_io[29] lpopamp_in+ / comparator_in– / mprj_io[30] lpopamp_out / mprj_io[31]; hsxo_xin / mprj_io[32] hsxo_xout / mprj_io[33]; bias_trim_in / mprj_io[35] mprj_io[36] mprj_io[37]; vddio; vccd; vssd2; vdda2; vssa2; vccd2

source_100_0 / hsxo_out / bandgap_out / mprj_io[34]

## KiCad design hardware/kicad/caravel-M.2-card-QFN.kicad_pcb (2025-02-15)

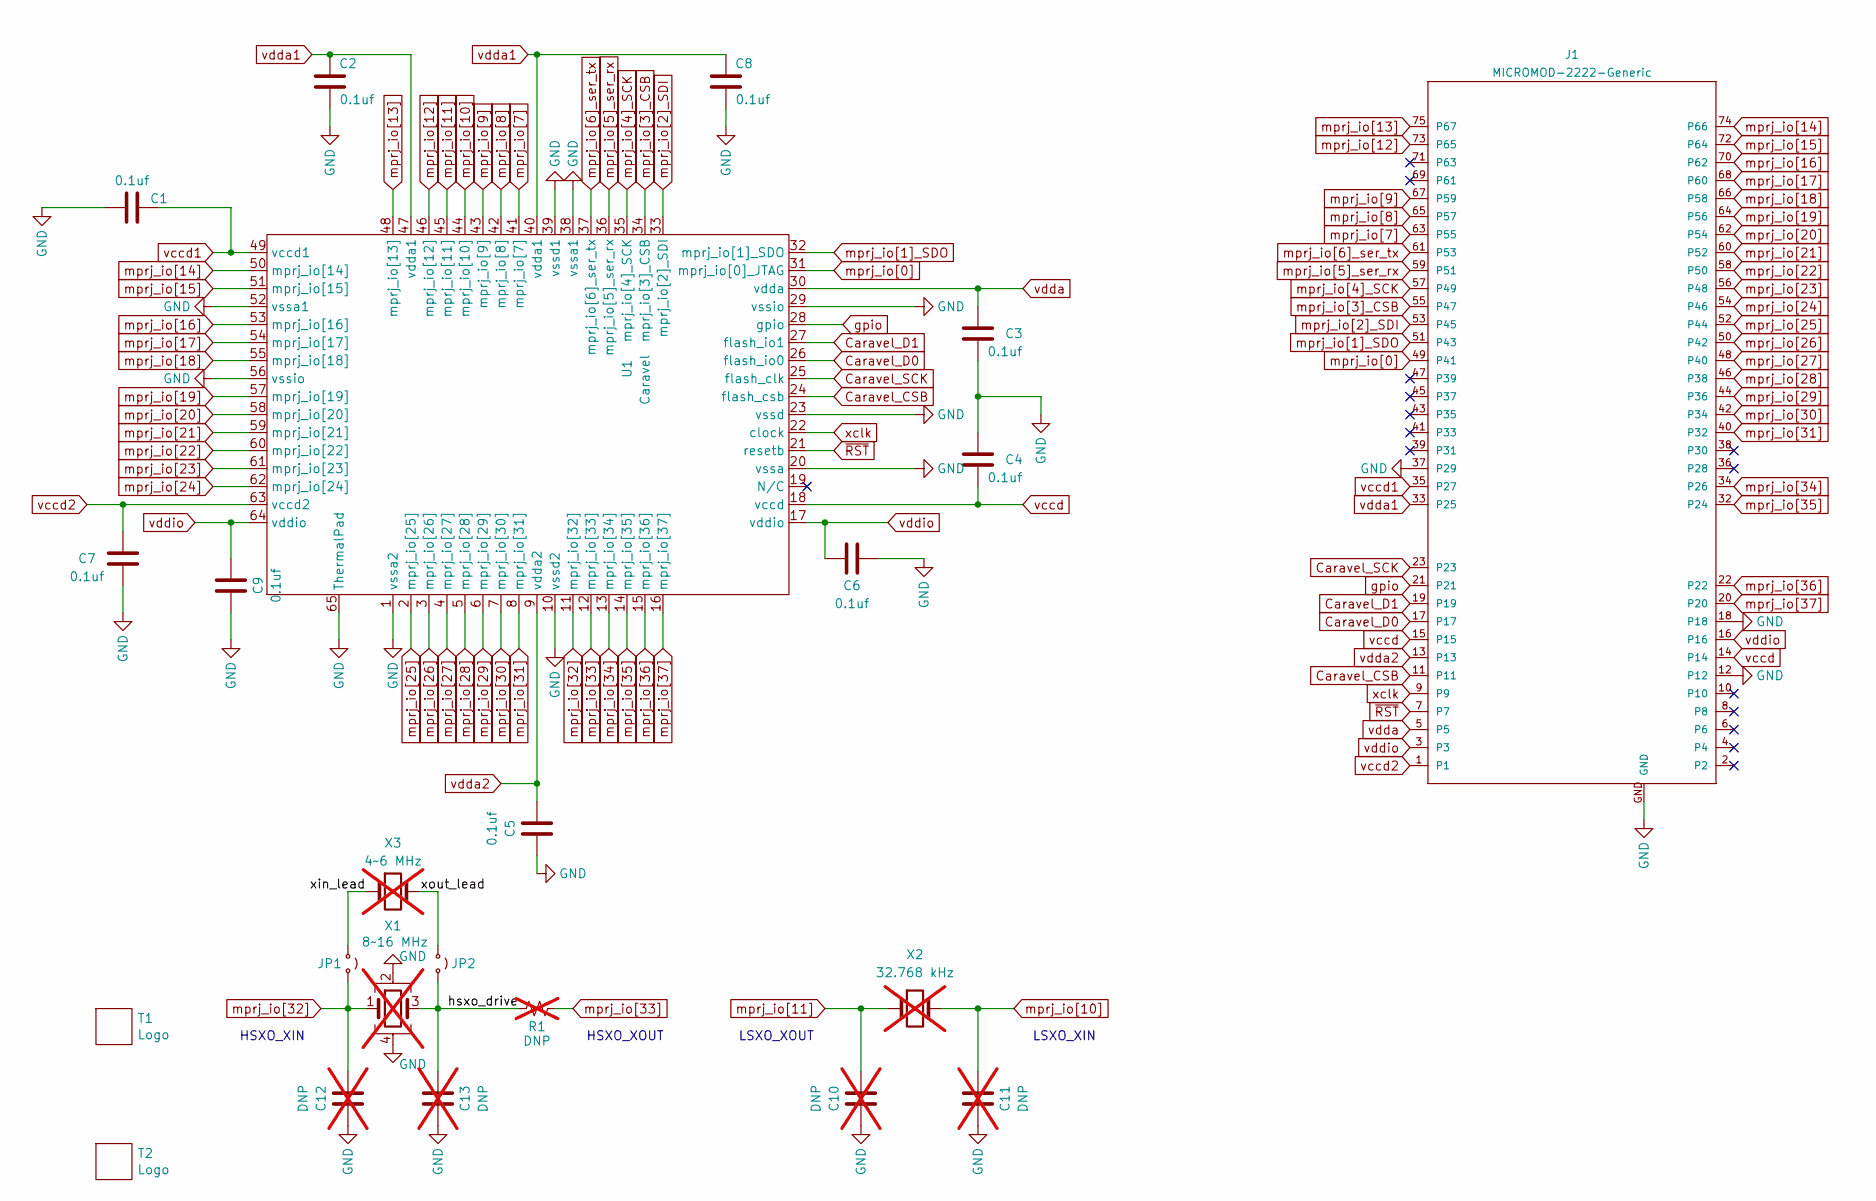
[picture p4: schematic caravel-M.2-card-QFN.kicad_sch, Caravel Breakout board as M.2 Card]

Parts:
C1, C2, C3, C4, C5, C6, C7, C8, C9: 0.1uf; C_0402_1005Metric
C10, C11: DNP; C_0402_1005Metric; not fitted
C12, C13: DNP; C_0402_1005Metric_Pad0.74x0.62mm_HandSolder; not fitted
J1: MICROMOD-2222-Generic; MicroMod-M.2-CARD-E-22
JP1, JP2: Jumper_2_Small_Open; Fuse_0402_1005Metric
R1: DNP; R_0402_1005Metric_Pad0.72x0.64mm_HandSolder; not fitted
T1: Logo; logo_small
T2: Logo; ef_logo
U1: Caravel; QFN-64-1EP_9x9mm_P0.5mm_EP7.65x7.65mm
X1: 8~16 MHz; Crystal_SMD_3225-4Pin_3.2x2.5mm; not fitted
X2: 32.768 kHz; Crystal_SMD_2012-2Pin_2.0x1.2mm; not fitted
X3: 4~6 MHz; Crystal_HC49-U_Vertical; not fitted

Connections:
/hsxo_drive: C13.1, JP2.2 (B), R1.1, X1.3
/xin_lead: JP1.1 (A), X3.1
/xout_lead: JP2.1 (A), X3.2
Caravel_CSB: J1.11, U1.24 (flash_csb)
Caravel_D0: J1.17, U1.26 (flash_io0)
Caravel_D1: J1.19, U1.27 (flash_io1)
Caravel_SCK: J1.23, U1.25 (flash_clk)
GND: C1.1, C2.2, C3.2, C4.1, C5.1, C6.1, C7.1, C8.2, C9.1, C10.1, C11.2, C12.1, C13.2, J1.12, J1.18, J1.37 (P29), J1.GND, U1.1 (vssa2), U1.10 (vssd2), U1.20 (vssa), U1.23 (vssd), U1.29 (vssio), U1.38 (vssa1), U1.39 (vssd1), U1.52 (vssa1), U1.56 (vssio), U1.65 (ThermalPad), X1.2, X1.4
gpio: J1.21, U1.28 (gpio)
mprj_io[0]: J1.49 (P41), U1.31 (mprj_io[0]_JTAG)
mprj_io[1]_SDO: J1.51 (P43), U1.32 (mprj_io[1]_SDO)
mprj_io[2]_SDI: J1.53 (P45), U1.33 (mprj_io[2]_SDI)
mprj_io[3]_CSB: J1.55 (P47), U1.34 (mprj_io[3]_CSB)
mprj_io[4]_SCK: J1.57 (P49), U1.35 (mprj_io[4]_SCK)
mprj_io[5]_ser_rx: J1.59 (P51), U1.36 (mprj_io[5]_ser_rx)
mprj_io[6]_ser_tx: J1.61 (P53), U1.37 (mprj_io[6]_ser_tx)
mprj_io[7]: J1.63 (P55), U1.41 (mprj_io[7])
mprj_io[8]: J1.65 (P57), U1.42 (mprj_io[8])
mprj_io[9]: J1.67 (P59), U1.43 (mprj_io[9])
mprj_io[10]: C11.1, U1.44 (mprj_io[10]), X2.2
mprj_io[11]: C10.2, U1.45 (mprj_io[11]), X2.1
mprj_io[12]: J1.73 (P65), U1.46 (mprj_io[12])
mprj_io[13]: J1.75 (P67), U1.48 (mprj_io[13])
mprj_io[14]: J1.74 (P66), U1.50 (mprj_io[14])
mprj_io[15]: J1.72 (P64), U1.51 (mprj_io[15])
mprj_io[16]: J1.70 (P62), U1.53 (mprj_io[16])
mprj_io[17]: J1.68 (P60), U1.54 (mprj_io[17])
mprj_io[18]: J1.66 (P58), U1.55 (mprj_io[18])
mprj_io[19]: J1.64 (P56), U1.57 (mprj_io[19])
mprj_io[20]: J1.62 (P54), U1.58 (mprj_io[20])
mprj_io[21]: J1.60 (P52), U1.59 (mprj_io[21])
mprj_io[22]: J1.58 (P50), U1.60 (mprj_io[22])
mprj_io[23]: J1.56 (P48), U1.61 (mprj_io[23])
mprj_io[24]: J1.54 (P46), U1.62 (mprj_io[24])
mprj_io[25]: J1.52 (P44), U1.2 (mprj_io[25])
mprj_io[26]: J1.50 (P42), U1.3 (mprj_io[26])
mprj_io[27]: J1.48 (P40), U1.4 (mprj_io[27])
mprj_io[28]: J1.46 (P38), U1.5 (mprj_io[28])
mprj_io[29]: J1.44 (P36), U1.6 (mprj_io[29])
mprj_io[30]: J1.42 (P34), U1.7 (mprj_io[30])
mprj_io[31]: J1.40 (P32), U1.8 (mprj_io[31])
mprj_io[32]: C12.2, JP1.2 (B), U1.11 (mprj_io[32]), X1.1
mprj_io[33]: R1.2, U1.12 (mprj_io[33])
mprj_io[34]: J1.34 (P26), U1.13 (mprj_io[34])
mprj_io[35]: J1.32 (P24), U1.14 (mprj_io[35])
mprj_io[36]: J1.22, U1.15 (mprj_io[36])
mprj_io[37]: J1.20, U1.16 (mprj_io[37])
vccd: C4.2, J1.14, J1.15, U1.18 (vccd)
vccd1: C1.2, J1.35 (P27), U1.49 (vccd1)
vccd2: C7.2, J1.1, U1.63 (vccd2)
vdda: C3.1, J1.5, U1.30 (vdda)
vdda1: C2.1, C8.1, J1.33 (P25), U1.40 (vdda1), U1.47 (vdda1)
vdda2: C5.2, J1.13, U1.9 (vdda2)
vddio: C6.2, C9.2, J1.3, J1.16, U1.17 (vddio), U1.64 (vddio)
xclk: J1.9, U1.22 (clock)
~RST: J1.7, U1.21 (resetb)

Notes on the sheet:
LSXO_XOUT
HSXO_XIN
LSXO_XIN
HSXO_XOUT

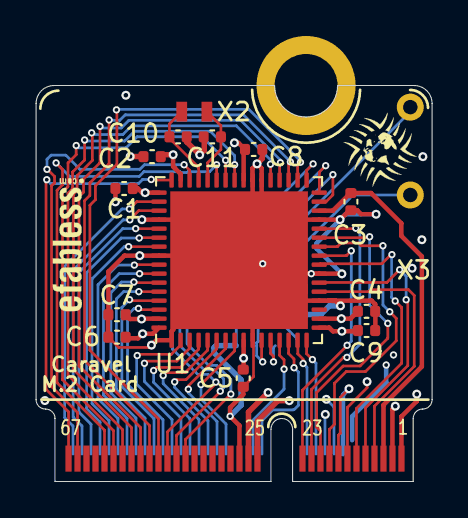
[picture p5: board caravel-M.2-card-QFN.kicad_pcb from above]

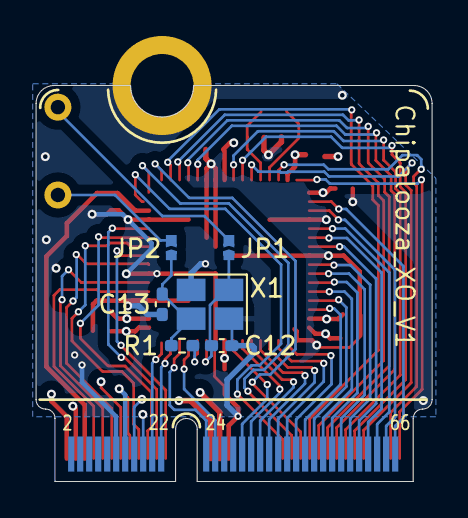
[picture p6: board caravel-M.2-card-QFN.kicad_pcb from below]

Board: 4 copper layers, 22.0 x 22.0 mm, 23 parts (6 on the bottom side), 56 nets.

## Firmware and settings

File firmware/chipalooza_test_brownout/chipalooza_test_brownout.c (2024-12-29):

#include <defs.h>
#include <chipalooza_stubs.h>

/*
 *-----------------------------------------------------------
 * chipalooza_test_brownout.c:
 *-----------------------------------------------------------
 * Written by Tim Edwards, Efabless Corporation
 * December 11, 2024
 *-----------------------------------------------------------
 *
 * Board-level preparation:
 * 1) connect vccd1 to 1.8V
 * 2) connect vccd2 to 1.8V
 * 3) connect vdda1 to 3.3V
 * 4) connect vdda2 to 3.3V
 * 5) connect GPIO 35 to 3.3V (for biasgen trim)
 *
 * Firmware preparation:
 * 1) set all GPIOs to analog mode (config_io, above)
 *    except for GPIO 0, 1, and 5,  which is are user
 *    digital outputs, and GPIO 25 to 33, which are
 *    management digital inputs.  Note that use of
 *    GPIO 1 as an output prevents use of the SPI, so
 *    reset w/power cycling is required to re-program
 *    the flash.
 * 2) disable all power supplies
 * 3) Take 1.2V reference from GPIO 9.
 *
 * Map the following digital inputs to project inputs:
 * GPIO 25	otrip 0
 * GPIO 26	otrip 1 
 * GPIO 27	otrip 2
 * GPIO 28	vtrip 0
 * GPIO 29	vtrip 1
 * GPIO 30	vtrip 2
 * GPIO 31	isel
 * GPIO 32	force rc on
 * GPIO 33	force rc off
 * GPIO 34	one-shot mode
 * GPIO 36	timeout (digital output)
 *
 *-----------------------------------------------------------
 * 1st test:  Check brownout detector
 *-----------------------------------------------------------
 *
 * 1) enable power supply for brownout detector
 * 2) enable the brownout detector
 * 3) enable the brownout detector bias (200nA)
 * 4) power supply monitor is GPIO 14 (no ESD protection)
 * 5) view digital outputs from GPIO 0 (main output),
 *    GPIO 1 (dcomp), and GPIO 2 (vunder)
 *
 * Basic functional test:  Output should go high (low?)
 * whenever the vdda1 power supply is less than the
 * specified trip point.  There are two trip points
 * corresponding to two different outputs.
 *
 *-----------------------------------------------------------
 * 1st test:  Check brownout detector
 *-----------------------------------------------------------
 *
 * Measure at different values of trip points, and check
 * operation with internal and external bias.
 *
 * Program:  Use digital input pins to set trip point and
 * select current bias.
 * Current bias select: (1 bit) on GPIO 31.  Set GPIO to be a
 * pull-down input, then control value from the Digilent.
 * The program periodically samples the value and applies it
 * to the logic analyzer.
 *
 * All other digital inputs are treated similarly:
 *
 * Main output trip point: (3 bits) on GPIO 25 to GPIO 27.
 * vunder output trip point: (3 bits) on GPIO 28 to 30.
 *
 * Force RC oscillator always on: (1 bit) GPIO 32
 * Force RC oscillator always off: (1 bit) GPIO 33
 *
 * Capture timed-out signal from la_data_out[117]
 * and output on GPIO 36.
 *
 * One-shot mode triggers on GPIO 34.
 *
 */

// --------------------------------------------------------
// Firmware routines
// --------------------------------------------------------

void delay(const int d)
{
    /* Configure timer for a single-shot countdown */
    reg_timer0_config = 0;
    reg_timer0_data = d;
    reg_timer0_config = 1;

    // Loop, waiting for value to reach zero
    reg_timer0_update = 1;  // latch current value
    while (reg_timer0_value > 0) {
	reg_timer0_update = 1;
    }
}

void config_io() {

    reg_mprj_io_0 = GPIO_MODE_USER_STD_OUTPUT;

    /* NOTE: SPI is not functional! */
    reg_mprj_io_1 = GPIO_MODE_USER_STD_OUTPUT;
    reg_mprj_io_2 = GPIO_MODE_USER_STD_OUTPUT;
    reg_mprj_io_3 = GPIO_MODE_MGMT_STD_INPUT_NOPULL;
    reg_mprj_io_4 = GPIO_MODE_MGMT_STD_INPUT_NOPULL;

    reg_mprj_io_5 = GPIO_MODE_USER_STD_OUTPUT;
    reg_mprj_io_6 = GPIO_MODE_MGMT_STD_ANALOG;
    reg_mprj_io_7 = GPIO_MODE_MGMT_STD_ANALOG;
    reg_mprj_io_8 = GPIO_MODE_MGMT_STD_ANALOG;
    reg_mprj_io_9 = GPIO_MODE_MGMT_STD_ANALOG;
    reg_mprj_io_10 = GPIO_MODE_MGMT_STD_ANALOG;
    reg_mprj_io_11 = GPIO_MODE_MGMT_STD_ANALOG;
    reg_mprj_io_12 = GPIO_MODE_MGMT_STD_ANALOG;
    reg_mprj_io_13 = GPIO_MODE_MGMT_STD_ANALOG;
    reg_mprj_io_14 = GPIO_MODE_MGMT_STD_ANALOG;
    reg_mprj_io_15 = GPIO_MODE_MGMT_STD_ANALOG;
    reg_mprj_io_16 = GPIO_MODE_MGMT_STD_ANALOG;
    reg_mprj_io_17 = GPIO_MODE_MGMT_STD_ANALOG;
    reg_mprj_io_18 = GPIO_MODE_MGMT_STD_ANALOG;

    reg_mprj_io_19 = GPIO_MODE_MGMT_STD_ANALOG;
    reg_mprj_io_20 = GPIO_MODE_MGMT_STD_ANALOG;
    reg_mprj_io_21 = GPIO_MODE_MGMT_STD_ANALOG;
    reg_mprj_io_22 = GPIO_MODE_MGMT_STD_ANALOG;
    reg_mprj_io_23 = GPIO_MODE_MGMT_STD_ANALOG;
    reg_mprj_io_24 = GPIO_MODE_MGMT_STD_ANALOG;
    reg_mprj_io_25 = GPIO_MODE_MGMT_STD_INPUT_PULLDOWN;
    reg_mprj_io_26 = GPIO_MODE_MGMT_STD_INPUT_PULLDOWN;
    reg_mprj_io_27 = GPIO_MODE_MGMT_STD_INPUT_PULLDOWN;
    reg_mprj_io_28 = GPIO_MODE_MGMT_STD_INPUT_PULLDOWN;
    reg_mprj_io_29 = GPIO_MODE_MGMT_STD_INPUT_PULLDOWN;
    reg_mprj_io_30 = GPIO_MODE_MGMT_STD_INPUT_PULLDOWN;
    reg_mprj_io_31 = GPIO_MODE_MGMT_STD_INPUT_PULLDOWN;
    reg_mprj_io_32 = GPIO_MODE_MGMT_STD_INPUT_PULLDOWN;
    reg_mprj_io_33 = GPIO_MODE_MGMT_STD_INPUT_PULLDOWN;
    reg_mprj_io_34 = GPIO_MODE_MGMT_STD_INPUT_PULLDOWN;
    reg_mprj_io_35 = GPIO_MODE_MGMT_STD_ANALOG;
    reg_mprj_io_36 = GPIO_MODE_MGMT_STD_OUTPUT;
    reg_mprj_io_37 = GPIO_MODE_MGMT_STD_ANALOG;
}


void main()
{
    uint8_t isel, otrip, vtrip, oneshot, timeout;
    uint32_t value, allgpio;

    reg_gpio_mode1 = 1;
    reg_gpio_mode0 = 0;
    reg_gpio_ien = 1;
    reg_gpio_oe = 1;

    reg_mprj_datah = 0;
    reg_mprj_datal = 0;

    config_io();

    reg_mprj_xfer = 1;
    while (reg_mprj_xfer == 1);

    // Initialize controls into the user project through the
    // logic analyzer interface.  This routine also powers down
    // all of the power switches.

    init_logic_analyzer();

    // Enable the power switch to the brownout detector
    brownout_powerup();

    // Enable the 1.2V reference voltage to the brownout detector
    brownout_vbg_enable();

    // Enable the bias current to the brownout detector
    brownout_bias_enable();

    // Enable the brownout detector itself
    brownout_enable();

    // Set brownout detector 1st trip point
    brownout_set_otrippoint(0);

    // Set brownout detector 2nd trip point
    brownout_set_vtrippoint(0);

    // Set brownout detector current source select
    brownout_select_internal_bias();

    // That's all!  Now if the LED on the board is blinking,
    // GPIO 0 should be the digital encoding of the state
    // vdda1 < (otrip point).

    // Proceed with the blink test.  For most measurements,
    // this should not be enabled to keep the digital
    // environment quieter for analog measurements.

    reg_gpio_out = 1; // OFF

    reg_mprj_datal = 0x00000000;
    reg_mprj_datah = 0x00000000;

    isel = 0;
    otrip = 0;
    vtrip = 0;

    while(1) {

	/* Blink LED */

	reg_gpio_out = 0x0;
	delay(1000000);
	reg_gpio_out = 0x1;
	delay(1000000);

	/* Sample current source select value, applied externally */
	/* on GPIO 31						  */

	allgpio = reg_mprj_datal;
        value = ((allgpio >> 31) & 0x1);
	if (value != isel) {
	    isel = value;
	    if (isel == 1)
		brownout_select_external_bias();
	    else
		brownout_select_internal_bias();
	}

	/* Sample 1st trip point value, applied externally on GPIO 27->25 */

	value = ((allgpio >> 25) & 0x7);
	if (value != otrip) {
	    otrip = value;
	    brownout_set_otrippoint(otrip);
	}

	/* Sample 2nd trip point value, applied externally on GPIO 30->28 */

	value = ((allgpio >> 28) & 0x7);
	if (value != vtrip) {
	    vtrip = value;
	    brownout_set_vtrippoint(vtrip);
	}

	/* Sample one-shot mode, applied externally on GPIO 34 */
	allgpio = reg_mprj_datah;
	value = ((allgpio >> 2) & 0x1);
	if (value != oneshot) {
	    oneshot = value;
	    if (oneshot == 1)
		brownout_oneshot_mode();
	    else
		brownout_continuous_mode();
	}

	/* Sample timeout, and apply externally to GPIO 36 */
	value = brownout_get_timeout();
	if (value != timeout) {
	    timeout = value;
	    reg_mprj_datah = (timeout & 0x1) << 4;
	}
    }
}

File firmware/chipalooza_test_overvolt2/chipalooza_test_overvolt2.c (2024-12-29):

#include <defs.h>
#include <chipalooza_stubs.h>

/*
 *-----------------------------------------------------------
 * chipalooza_test_overvolt2.c:
 *-----------------------------------------------------------
 * Written by Tim Edwards, Efabless Corporation
 * November 28, 2024
 *-----------------------------------------------------------
 *
 * Board-level preparation:
 * 1) connect vccd1 to 1.8V
 * 2) connect vccd2 to 1.8V
 * 3) connect vdda1 to 3.3V
 * 4) connect vdda2 to 3.3V
 * 5) connect GPIO 35 to 3.3V (for biasgen trim)
 *
 * Digilent setup:
 * V+ to vdda1
 * W1 set at constant 1.2V to GPIO 9
 * 1+ to GPIO 13
 * digital channels 0->3 to GPIO 0 and 6->8
 *
 * NOTE:  The digital input bits are not all together
 * because GPIO 5 is used for the UART by default and
 * is strongly pulled high.
 *
 * Firmware preparation:
 * 1) set all GPIOs to analog mode (config_io, above)
 *    except for GPIO 13, which is a user digital output
 * 2) disable all power supplies
 *
 *-----------------------------------------------------------
 * 1st test:  Check overvoltage
 *-----------------------------------------------------------
 *
 * 1) enable power supply for overvoltage detector
 * 2) enable the overvoltage detector
 * 3) enable the overvoltage detector bias (400nA)
 * 4) enable the overvoltage detector bandgap input (1.2V)
 *	(Note:  This needs to be externally supplied)
 * 5) power supply monitor is GPIO 18 (no ESD protection)
 * 6) view digital output from GPIO 13
 *
 * Basic functional test:  Output should go high whenever
 * the vdda1 supply exceeds the default threshold
 *
 * Note that this circuit is powered off of vdda1, which
 * also powers the current bias generator, so it is not
 * possible to decouple the two.
 *
 *-----------------------------------------------------------
 * 2nd test:  Check trim
 *-----------------------------------------------------------
 *
 * Measure at different values of voltage trim.
 *
 * Basic functional test:  Output should go high whenever
 * the vdda1 supply exceeds the threshold set by the trip
 * point.  Use GPIO 8->6, 0 connected to Digilent channels
 * 3->0 to control the 4-bit threshold setting (see code
 * below).
 *
 */

// --------------------------------------------------------
// Firmware routines
// --------------------------------------------------------

void delay(const int d)
{
    /* Configure timer for a single-shot countdown */
    reg_timer0_config = 0;
    reg_timer0_data = d;
    reg_timer0_config = 1;

    // Loop, waiting for value to reach zero
    reg_timer0_update = 1;  // latch current value
    while (reg_timer0_value > 0) {
	reg_timer0_update = 1;
    }
}

void config_io() {

    /* For digital input setting trippoint level (low bit) */
    reg_mprj_io_0 = GPIO_MODE_MGMT_STD_INPUT_PULLDOWN;

    /* Keep SPI functional */
    reg_mprj_io_1 = GPIO_MODE_MGMT_STD_OUTPUT;
    reg_mprj_io_2 = GPIO_MODE_MGMT_STD_INPUT_NOPULL;
    reg_mprj_io_3 = GPIO_MODE_MGMT_STD_INPUT_NOPULL;
    reg_mprj_io_4 = GPIO_MODE_MGMT_STD_INPUT_NOPULL;

    reg_mprj_io_5 = GPIO_MODE_MGMT_STD_ANALOG;
    /* For digital input setting trippoint level (upper 3 bits) */
    reg_mprj_io_6 = GPIO_MODE_MGMT_STD_INPUT_PULLDOWN;
    reg_mprj_io_7 = GPIO_MODE_MGMT_STD_INPUT_PULLDOWN;
    reg_mprj_io_8 = GPIO_MODE_MGMT_STD_INPUT_PULLDOWN;

    /* For 1.2V input */
    reg_mprj_io_9 = GPIO_MODE_MGMT_STD_ANALOG;
    reg_mprj_io_10 = GPIO_MODE_MGMT_STD_ANALOG;
    reg_mprj_io_11 = GPIO_MODE_MGMT_STD_ANALOG;
    reg_mprj_io_12 = GPIO_MODE_MGMT_STD_ANALOG;

    /* Overvoltage detector digital output is on GPIO 13 */
    reg_mprj_io_13 = GPIO_MODE_USER_STD_OUTPUT;

    reg_mprj_io_14 = GPIO_MODE_MGMT_STD_ANALOG;
    reg_mprj_io_15 = GPIO_MODE_MGMT_STD_ANALOG;
    reg_mprj_io_16 = GPIO_MODE_MGMT_STD_ANALOG;
    reg_mprj_io_17 = GPIO_MODE_MGMT_STD_ANALOG;
    reg_mprj_io_18 = GPIO_MODE_MGMT_STD_ANALOG;

    reg_mprj_io_19 = GPIO_MODE_MGMT_STD_ANALOG;
    reg_mprj_io_20 = GPIO_MODE_MGMT_STD_ANALOG;
    reg_mprj_io_21 = GPIO_MODE_MGMT_STD_ANALOG;
    reg_mprj_io_22 = GPIO_MODE_MGMT_STD_ANALOG;
    reg_mprj_io_23 = GPIO_MODE_MGMT_STD_ANALOG;
    reg_mprj_io_24 = GPIO_MODE_MGMT_STD_ANALOG;
    reg_mprj_io_25 = GPIO_MODE_MGMT_STD_ANALOG;
    reg_mprj_io_26 = GPIO_MODE_MGMT_STD_ANALOG;
    reg_mprj_io_27 = GPIO_MODE_MGMT_STD_ANALOG;
    reg_mprj_io_28 = GPIO_MODE_USER_STD_ANALOG;
    reg_mprj_io_29 = GPIO_MODE_MGMT_STD_ANALOG;
    reg_mprj_io_30 = GPIO_MODE_MGMT_STD_ANALOG;
    reg_mprj_io_31 = GPIO_MODE_MGMT_STD_ANALOG;
    reg_mprj_io_32 = GPIO_MODE_MGMT_STD_ANALOG;
    reg_mprj_io_33 = GPIO_MODE_MGMT_STD_ANALOG;
    reg_mprj_io_34 = GPIO_MODE_MGMT_STD_ANALOG;
    reg_mprj_io_35 = GPIO_MODE_MGMT_STD_ANALOG;
    reg_mprj_io_36 = GPIO_MODE_MGMT_STD_ANALOG;
    reg_mprj_io_37 = GPIO_MODE_MGMT_STD_ANALOG;
}


void main()
{
    uint8_t vtrip;
    uint32_t value, allgpio;

    reg_gpio_mode1 = 1;
    reg_gpio_mode0 = 0;
    reg_gpio_ien = 1;
    reg_gpio_oe = 1;

    reg_mprj_datah = 0;
    reg_mprj_datal = 0;

    config_io();

    reg_mprj_xfer = 1;
    while (reg_mprj_xfer == 1);

    // Initialize controls into the user project through the
    // logic analyzer interface.  This routine also powers down
    // all of the power switches.

    init_logic_analyzer();

    // Enable the power switch to the overvoltage detector.
    overvoltage2_powerup();

    // Enable the bias current to the overvoltage detector.
    overvoltage2_bias_enable();

    // Enable the overvoltage detector
    // This also enables the 1.2V bandgap for the overvoltage detector.
    overvoltage2_enable();

    // Set overvoltage trip point
    overvoltage2_set_trippoint(0);

    // That's all!  Now if the LED on the board is blinking,
    // GPIO 13 should be the digital encoding of the state
    // V(vdda1) > V(trip).

    // Proceed with the blink test.  For most measurements,
    // this should not be enabled to keep the digital
    // environment quieter for analog measurements.

    reg_gpio_out = 1; // OFF

    reg_mprj_datal = 0x00000000;
    reg_mprj_datah = 0x00000000;

    vtrip = 0;

    while(1) {

	/* Blink LED */

	reg_gpio_out = 0x0;
	delay(1000000);
	reg_gpio_out = 0x1;
	delay(1000000);

	/* Sample trip point value, applied externally	*/
	/* on GPIO 8->6, 0				*/

	allgpio = reg_mprj_datal;
	value = (allgpio & 0x1) | ((allgpio >> 5) & 0xe);
	if ((uint8_t)value != vtrip) {
	    vtrip = (uint8_t)value;
	    overvoltage2_set_trippoint(vtrip);
	}
    }
}

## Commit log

2024-04-25 Uploading everything from local work. Chipalooza projects first attempt. Chip, chip, hooray!
    [analog_mux_sel1v8.sch, analog_wrapper_tb.sch, bias_generator.sch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]
2024-04-25 Update after LVS finished.
    [chipalooza_testchip1.sch, user_analog_project_wrapper.sch]
2024-04-25 Rewrote the assembly script to avoid trashing the standard cells and creating invalid GDS.
2024-04-26 Update after running precheck locally and fixing all outstanding errors.
    [isolated_switch.sch]
2024-04-26 Corrected one pin layer error that failed to get resolved in the last update (but was not noticed), and added the default lvs_config.json in the hopes that the run will not fail on the missing file (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
2024-04-27 Layout modifications for correcting antenna violations, and changes to possibly avoid an error on the OEB checks.
2024-04-29 Updated the README file with the complete list of digital controls and pin assignments.
2024-05-03 Updated files post-tapeout to make sure that the repository is LVS and DRC clean. Corresponds to changes made to each of the project repositories (in branches "tapeout_ci2404", pull requests to be ma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
    [analog_mux_sel1v8.sch, chipalooza_testchip1.sch, gate_drive.sch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]
2024-05-06 Removed the bandgap modified layouts and put them where they belong, in the repository from which they were taken. Added a Makefile target for cloning the IP block repositories locally. Reconstructed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
    [chipalooza_testchip1.sch]
2024-05-07 Corrected the logic analyzer connections, which were all backwards, with la_data_out connected where la_data_in should have been, and vice versa.
    [chipalooza_testchip1.sch, user_analog_project_wrapper.sch]
2024-05-08 Added a drawing of the package pinout with project pin names, and filled out the README file with additional clarifying details, such as lists ordered by package pin and by logic analyzer bit, and sp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
2024-12-29 Corrected the trip point voltage setting for the overvoltage1 circuit in chipalooza_util.c, which was truncating the 32 bit logic analyzer value to an 8-bit value.
2024-12-29 Corrected error in chipalooza_test_brownout.c that prevents compilation.
    [chipalooza_test_brownout.c]
2024-12-29 Corrected an error in the setting of the enable/disable bit for the Von Braun Labs' overvoltage detector. Changed the digital input bits for setting the trim to avoid GPIO 5, which is held high by th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
    [chipalooza_test_overvolt2.c]
2024-12-29 Corrected some code in chipalooza_test_brownout.c and added a missing routine to chipalooza_util.c to enable/disable the brownout circuit.
    [chipalooza_test_brownout.c]
2025-02-15 Added directory "hardware" with (gerber) files for a special M.2 daughter card design to be used with the test chip to allow crystals to be placed close to the chip package for testing the LSXO and H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
    [caravel-M.2-card-QFN-B_Cu.gbl, caravel-M.2-card-QFN-B_Fab.gbr, caravel-M.2-card-QFN-B_Mask.gbs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]
2025-02-15 Added KiCad design files for the custom M.2 daughter card (again, thanks to Brady Etz!).
    [caravel-M.2-card-QFN-B_Cu.gbl, caravel-M.2-card-QFN-B_Fab.gbr, caravel-M.2-card-QFN-B_Mask.gbs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]

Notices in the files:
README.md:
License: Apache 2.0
